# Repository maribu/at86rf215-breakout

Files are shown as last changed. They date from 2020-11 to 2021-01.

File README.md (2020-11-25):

AT86RF215 Breakout Board
========================

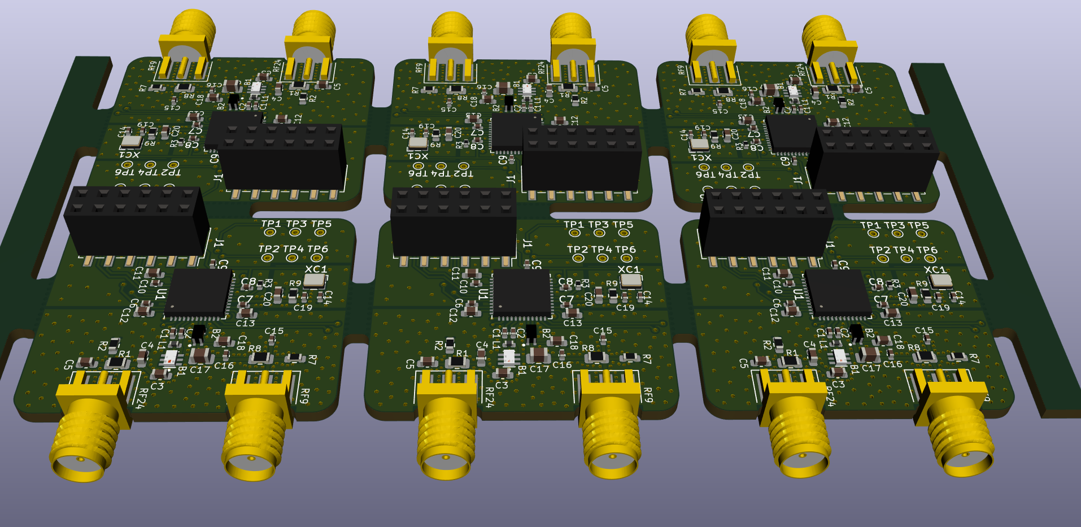
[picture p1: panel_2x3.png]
Panel of AT86RF215 Breakout Boards

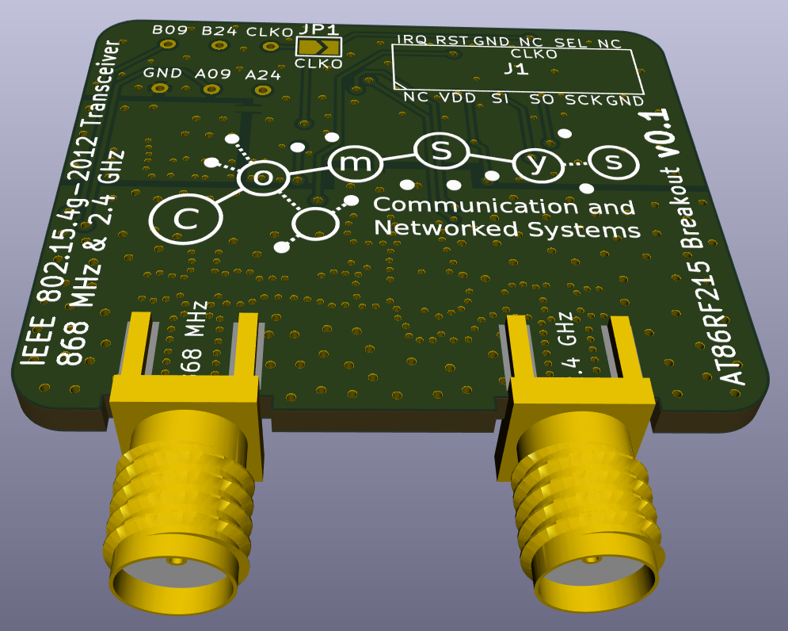
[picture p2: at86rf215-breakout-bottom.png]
AT86RF215 Breakout Board Bottom Side

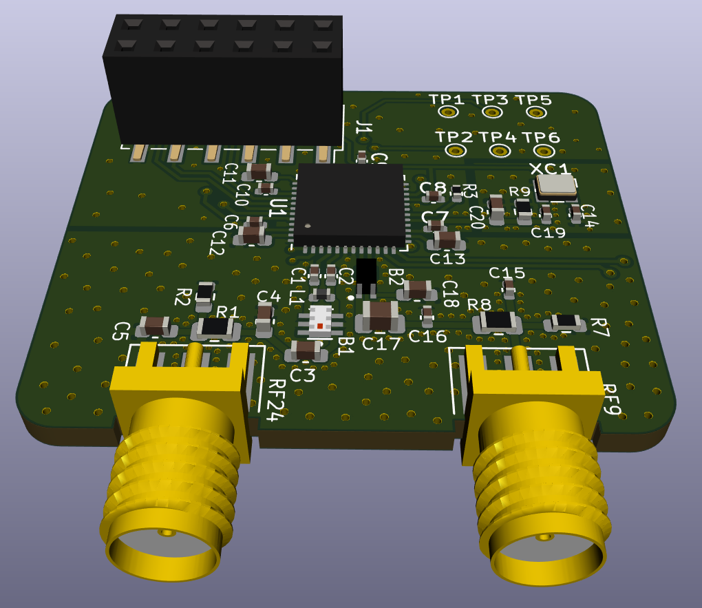
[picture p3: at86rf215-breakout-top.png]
AT86RF215 Breakout Board Top Side


This Repository contains an minimal AT86RF215 breakout board. The pin header
is compatible to the openlabs.co Raspberry Pi 802.15.4 radio. However, this
will not be a drop-in replacement as the software needs adjustment.

WARNING
=======

1. The PCB contains no shielding for the RF filter, which will result in lower
   sensitivity and higher noise in the transmitted signal compared to e.g. the
   AT86RF215-XPRO reference design.
2. It is highly recommended to not order PCBs based on this design as of now.
   While an earlier version seems to work flawlessly, this revision has not been
   tested yet.
3. There is absolutely no warranty.

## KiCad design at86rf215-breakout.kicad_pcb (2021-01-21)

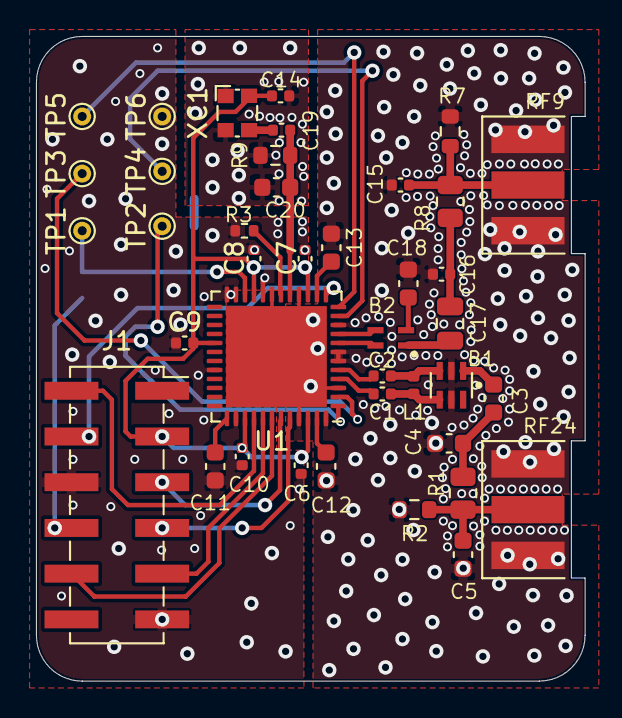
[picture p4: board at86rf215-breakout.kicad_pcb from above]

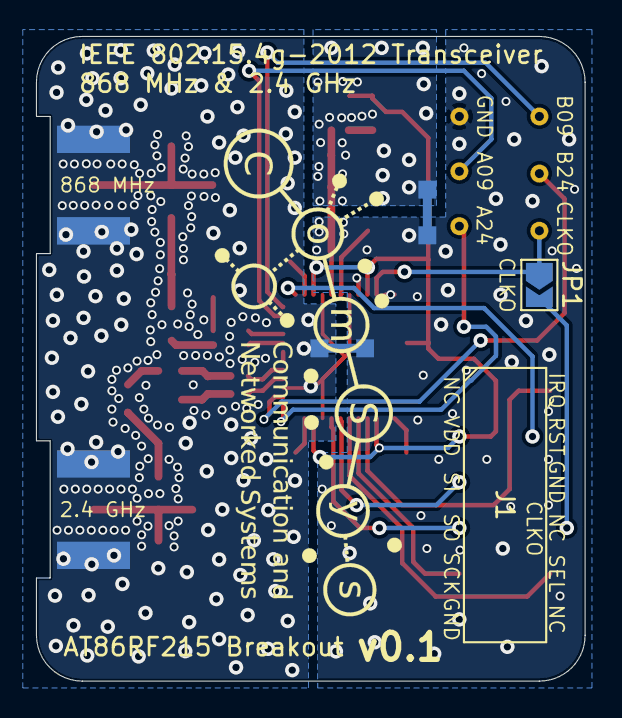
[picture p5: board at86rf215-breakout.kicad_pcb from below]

Board: 2 copper layers, 30.5 x 35.8 mm, 43 parts (3 on the bottom side), 35 nets.

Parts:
B1: Balun 2.4 GHz; 2450FB15A050
B2: Balun 868 MHz; DLW21SN900SQ2L
C1, C2: 1.8 pF; C_0402_1005Metric
C3: 0.8 pF; C_0603_1608Metric
C4, C5: 1.2 pF; C_0603_1608Metric
C6, C7, C8, C9, C10, C14: 100 nF; C_0402_1005Metric
C11, C12, C13: 1 µF; C_0603_1608Metric
C15, C16: 2.2 pF; C_0402_1005Metric
C17: 15 pF; C_0805_2012Metric
C18: 8.2 pF; C_0603_1608Metric
C19: 1 nF; C_0402_1005Metric
C20: 10 pF; C_0603_1608Metric
J1: RPi Header; PinSocket_2x06_P2.54mm_Vertical_SMD
JP1: solder jumper; SolderJumper-2_P1.3mm_Open_TrianglePad1.0x1.5mm
L1: 5.6 nH; L_0402_1005Metric
R1, R8: 0 Ω; R_0805_2012Metric
R2, R7, R9: 10 kΩ; R_0603_1608Metric
R3: 100 kΩ; R_0402_1005Metric
R4, R5: 0 Ω; R0
RF9, RF24: Antenna; Connector-SMA
TP1: CLKO; TestPoint_THTPad_D1.0mm_Drill0.5mm
TP2: FEA24; TestPoint_THTPad_D1.0mm_Drill0.5mm
TP3: FEB24; TestPoint_THTPad_D1.0mm_Drill0.5mm
TP4: FEA09; TestPoint_THTPad_D1.0mm_Drill0.5mm
TP5: FEB09; TestPoint_THTPad_D1.0mm_Drill0.5mm
TP6: GND; TestPoint_THTPad_D1.0mm_Drill0.5mm
U1: AT86RF215-ZU; QFN-48-1EP_7x7mm_P0.5mm_EP5.6x5.6mm
XC1: 26 MHz TCXO; IQD_LFTCXO078374REEL

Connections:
/ANT09: C15.1, R7.1, R8.2, RF9.1
/ANT09': C16.1, C17.2, R8.1
/ANT09'': B2.1, C17.1
/ANT24: C5.1, R1.2, R2.1, RF24.1
/ANT24': C3.1, C4.1, R1.1
/ANT24'': B1.1, C3.2
/AVDD0: C13.2, U1.14
/AVDD1: C12.2, U1.47
/Balun_GND: B2.2, C18.1
/CLKO: JP1.1, TP1.1, U1.22
/CLKO': J1.8, JP1.2
/DVDD: C11.2, U1.37
/FEA09: TP4.1, U1.11
/FEA24: TP2.1, U1.1
/FEB09: TP5.1, U1.12
/FEB24: TP3.1, U1.2
/IRQ: J1.2, U1.40
/MISO: J1.7, U1.44
/MOSI: J1.5, U1.43
/RFN09: B2.3, U1.9
/RFN24: C2.2, U1.5
/RFN24': B1.3, C2.1, L1.2
/RFP09: B2.4, U1.8
/RFP24: C1.2, U1.4
/RFP24': B1.4, C1.1, L1.1
/RST: J1.4, U1.13
/SCLK: J1.9, U1.41
/SEL: J1.10, U1.42
/TCXO: C19.1, C20.1, R9.1, U1.17
/TCXO': C19.2, XC1.3
GND: C6.1, C7.1, C8.1, C9.1, C10.1, C11.1, J1.6, J1.11, R3.1, R4.2, R5.2, TP6.1, U1.20, U1.23, U1.24, U1.32, U1.38
GND2: C14.2, C20.2, R4.1, R9.2, XC1.1, XC1.2
GNDA: B1.2, B1.5, C4.2, C5.2, C12.1, C13.1, C15.2, C16.2, C18.2, R2.2, R5.1, R7.2, RF9.2, RF24.2, U1.3, U1.6, U1.7, U1.10, U1.16, U1.19, U1.45, U1.48, U1.49
unnamed: R3.2, U1.18
VDD: C6.2, C7.2, C8.2, C9.2, C10.2, C14.1, J1.3, U1.15, U1.21, U1.29, U1.39, U1.46, XC1.4

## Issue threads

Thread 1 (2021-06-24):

differencial pins?

eljuligallego, 2021-06-24:
Hi,

the digital differential ports for data(TX and RX) and clock are not propagated so with this board is not possible to use it like with the [ATREB215-XPRO](https://ww1.microchip.com/downloads/en/DeviceDoc/Atmel-42398-ATREB215-XPRO-Extension-Board_UserGuide.pdf) eval board.

you plan to add this?.

maribu, 2021-06-24:
No, but feel free to open a pull request doing so, or to create a fork with this added.

eljuligallego, 2021-06-24:
OK, I can try.

any board/connector in mind?.

My idea is to connect a FPGA board compatible with lvds at this frequencies. something cheap and powerfull like the [EBAZ4205](https://github.com/xjtuecho/EBAZ4205).

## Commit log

2020-11-23 Update to v0.1
    - Use SMD instead for thru-hole pin header for lower assembly cost
    - Place pin header on top side, so that only one side needs SMD assembly
    - Move pin header to allow placement on MIoT-Lab Testbed Nodes
    [at86rf215-breakout.kicad_pcb, at86rf215-breakout.sch]
2020-11-25 Add custom panelization script
    The KiKit CLI cannot create a grid with boards rotated differently, so I created
    a custom script using KiKit to create the panels. This places two rows of the
    board with the SMA connector facing outward, so that they can be soldered on
    by the fab without breaking the boards of out the panel.
2020-11-26 Use same baluns as AT86RF215-XPRO
    [at86rf215-breakout.kicad_pcb, at86rf215-breakout.sch]
2020-11-30 Added test points
    [at86rf215-breakout.kicad_pcb, at86rf215-breakout.sch]
2020-12-01 Use different TCXO
    [at86rf215-breakout.kicad_pcb, at86rf215-breakout.sch]
2020-12-02 Change used TCXO
    [at86rf215-breakout.kicad_pcb, at86rf215-breakout.sch]
2020-12-18 Fixed footprint of TCXO
    Datasheet is in bottom view, not top view :-/
    [at86rf215-breakout.kicad_pcb]
2021-01-21 PCB: Untick "Keep upright" on labels
    This makes sure that the rotated PCBs on the panel have identically oriented
    silkscreen labels in both rows :-)
    [at86rf215-breakout.kicad_pcb]
